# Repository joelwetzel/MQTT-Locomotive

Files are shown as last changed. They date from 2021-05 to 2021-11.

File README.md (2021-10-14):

# MQTT-Locomotive

**Topics**

[Retrofit a conventional locomotive](Documentation/RetrofitALocomotive/README.md)

[Engine Microcontroller](Documentation/EngineMicrocontroller/README.md)

[Sound Microcontroller](Documentation/SoundMicrocontroller/README.md)

[Tach Calibrator](Documentation/TachCalibrator/README.md)

[Whistle Controller](Documentation/WhistleController/README.md)

[Power Supply](Documentation/PowerSupply/README.md)

[Control Panel](Documentation/ControlPanel/README.md)

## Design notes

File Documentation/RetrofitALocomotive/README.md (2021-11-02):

## Remove the Shell

This one has a conventional E-Unit.  No sound system.  Incandescent headlights and cab light.

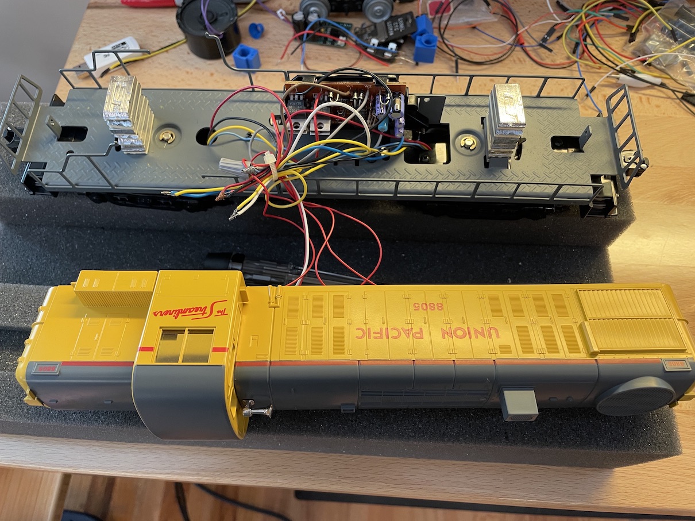
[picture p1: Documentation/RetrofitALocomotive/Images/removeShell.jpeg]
Remove the shell


---

## Cut wires and remove old E-Unit

Try to save as much wire as possible coming from the trucks, but don't worry about anything else.

This locomotive had weights stacked, creating a high center-of-gravity.  I'm going to relocate them down lower in the fuel tank.

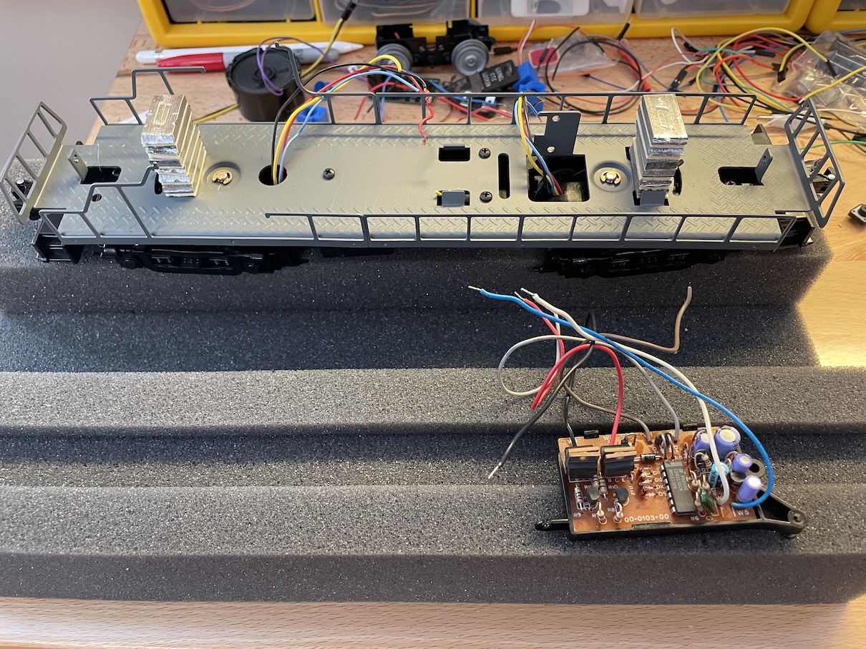
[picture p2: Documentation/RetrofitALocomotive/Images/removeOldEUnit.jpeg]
Cut wires


---

## Remove truck that will get the tachometer

Here I'm removing the front truck.  The opening for the wires is wider, which we'll need since we're adding extra wires for the tach.  We don't want it to resist turning.

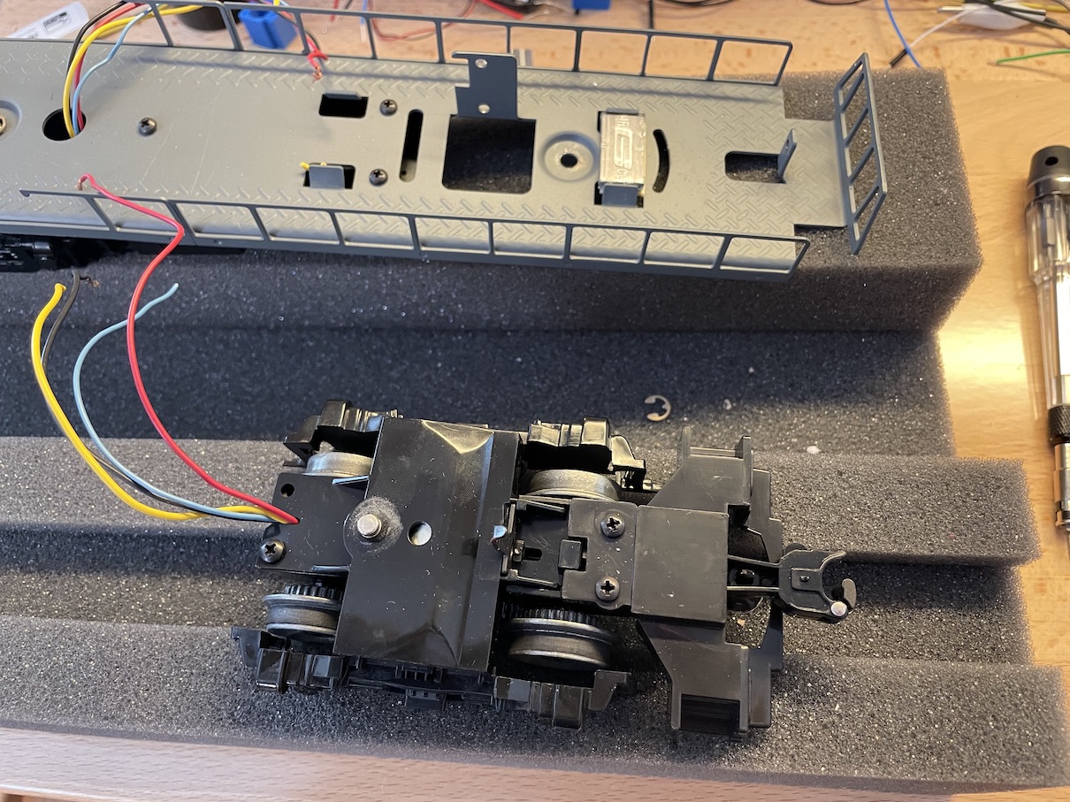
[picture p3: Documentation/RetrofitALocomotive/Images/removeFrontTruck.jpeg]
Remove front truck


---

## Wire/Glue/Test the tachometer

For this step, see [TachCalibrator Instructions](../TachCalibrator/README.md).

---

## Reinstall trucks

Here I have painted the trucks, and reinstalled them.  I have also moved most of the weights down into the fuel tank.

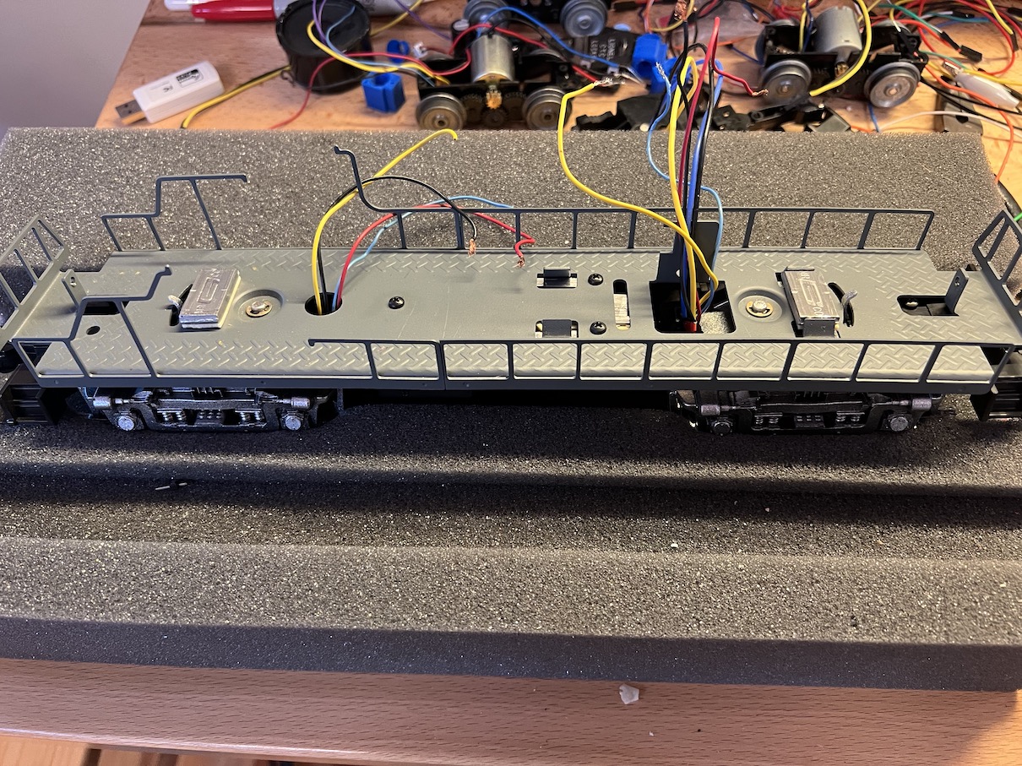
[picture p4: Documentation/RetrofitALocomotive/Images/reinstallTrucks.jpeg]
Reinstall trucks


---

## Power the motors

Install the motor driver and wire the truck motors to it.  Make sure to have lots of slack in these wires, because the trucks will turn and you don't want it to bind.

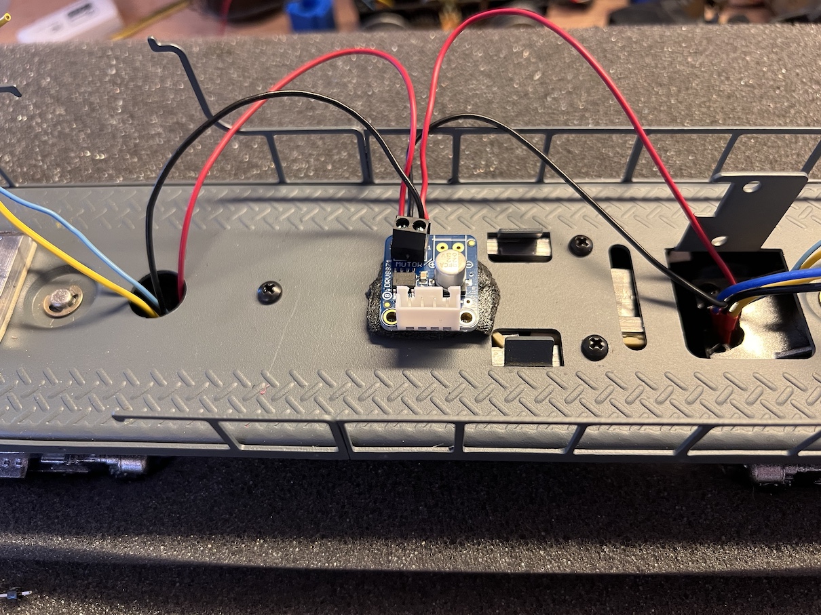
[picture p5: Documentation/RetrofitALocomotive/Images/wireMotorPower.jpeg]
Power the motors


---

## Power the smokestack

The motor driver for the smokestack needs an extra jumper soldered in on the back, from pin 1 to pin 4.

TODO

---

## Prepare the LED lights

This Alco RS-3 has dual headlights and a cab light.  I convert them to LEDs, and use heatshrink wrap to clean up the packaging.

It's important to solder a resistor in series.  I use 100ohm for the cab light, and 47ohm for the headlights.

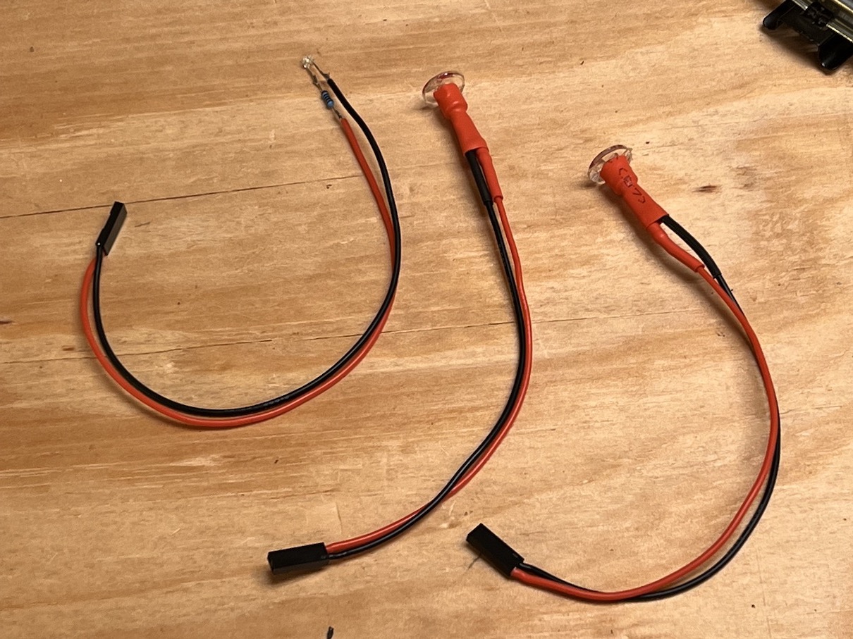
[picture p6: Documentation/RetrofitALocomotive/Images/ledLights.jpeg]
LED lights


You can reinstall them right away.

---

## Assemble and program the engine microcontroller and hat

1. Assemble the Wemos D1 Mini and the Engine Hat.  The Engine Microcontroller is detailed [here](../EngineMicrocontroller/README.md).
2. Build and upload the engine firmware.

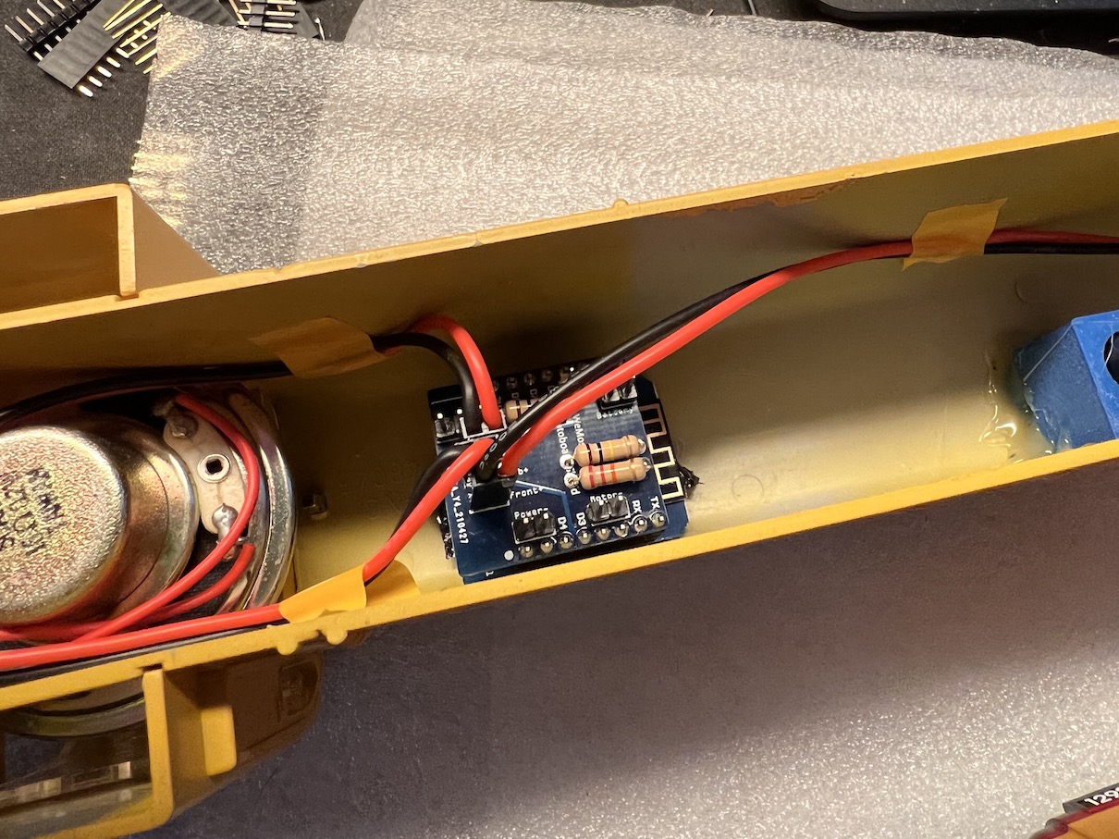
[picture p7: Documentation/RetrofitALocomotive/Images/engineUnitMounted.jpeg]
Mount the engine unit


---

## Assemble and program the sound microcontroller and hat

1. Assemble the Wemos D1 Mini and the Sound Hat.  The Sound Hat is detailed [here](../SoundMicrocontroller/README.md).
1. Build and upload the filesystem image.  It has the sound files.
2. Build and upload the sound firmware.
3. Test the sound.  You'll have both the engine and the sound ESP8266's still outside the chassis at this point.
4. Mount it in the body, with the usb port accessible.

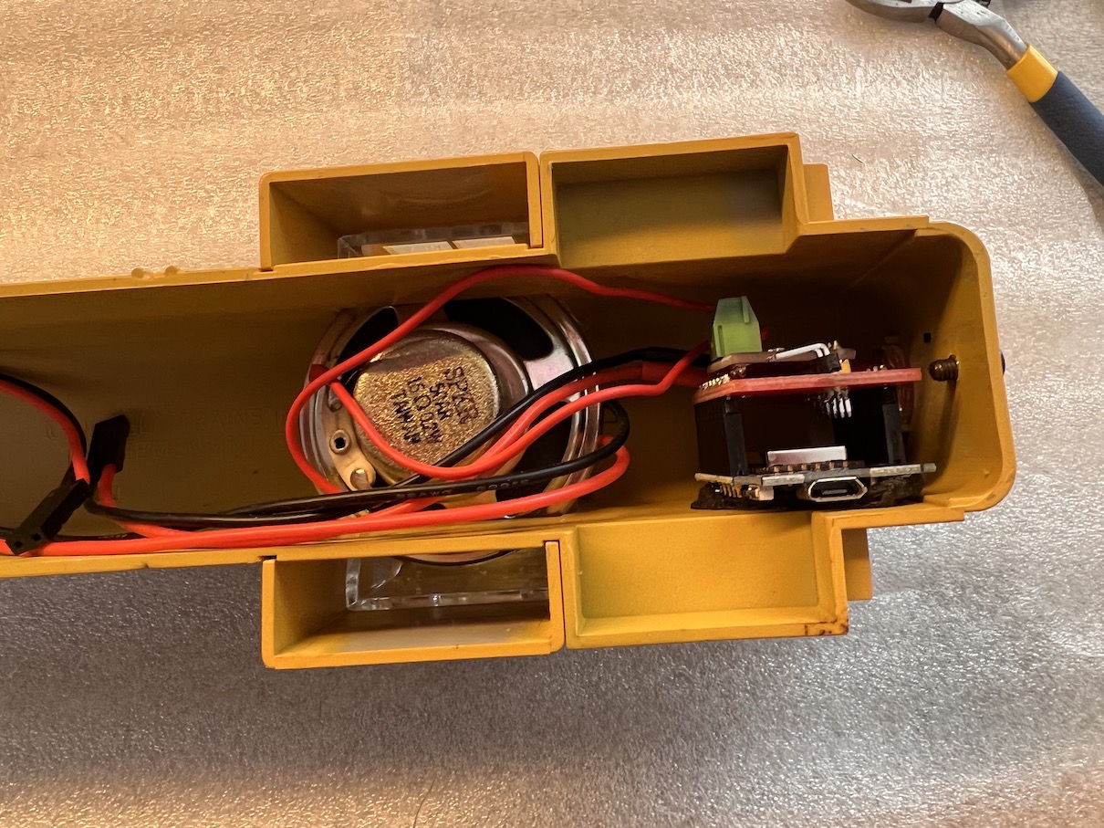
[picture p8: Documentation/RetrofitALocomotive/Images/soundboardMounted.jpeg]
Soundboard mounted


---

## Assemble the Power Supply PCB

The power supply is detailed [here](../PowerSupply/README.md).

---

** Get power from the trucks

Wire the truck power wires together and onto a Dupont connector that will go up to the power supply board.  Make sure to leave lots of slack.  The trucks will turn and you don't want it to bind.

I use twist connectors instead of soldered joints, because you might need to drop the trucks from the frame, while doing future maintenance.

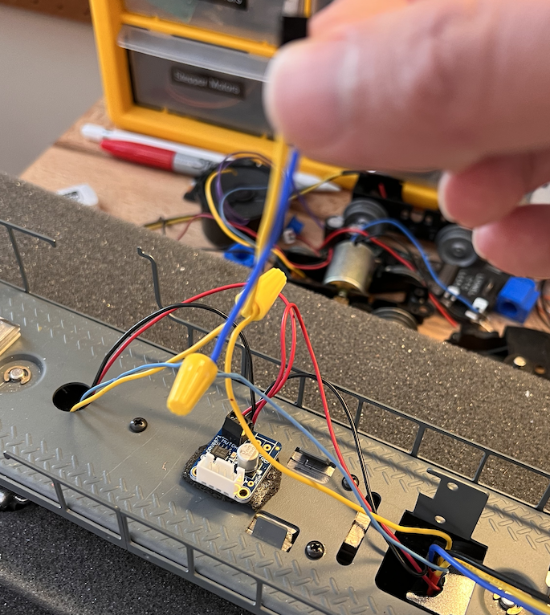
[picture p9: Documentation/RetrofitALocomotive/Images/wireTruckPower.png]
Wires from trucks


---

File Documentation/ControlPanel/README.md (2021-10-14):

# Control Panel

Here's the panel components wired up and tested, but not mounted in the panel yet:

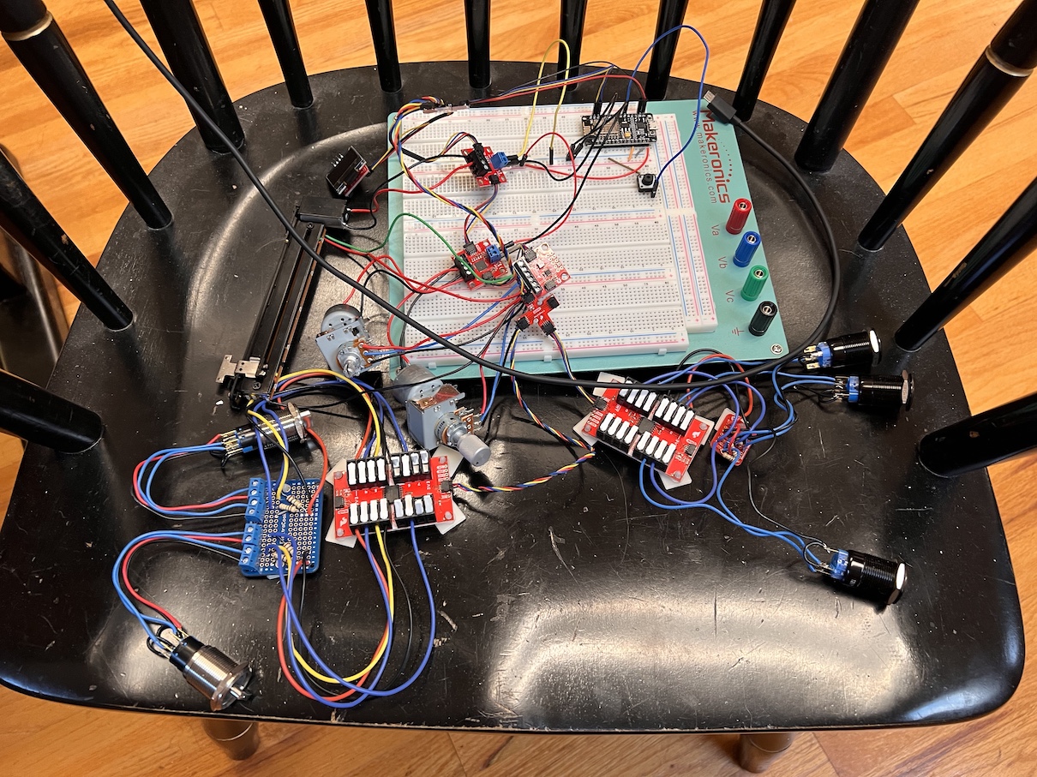
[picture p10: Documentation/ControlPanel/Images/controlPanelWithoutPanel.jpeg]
Control panel, sans panel


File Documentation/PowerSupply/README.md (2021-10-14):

# Power Supply

This board takes track power (~16V AC) as input.  It then:
- Rectifies to DC
- Smooths the waveform
- Provides 16V DC output
- Provides 5V DC output

---

## Fritzing File

[Fritzing file](PowerSupply.fzz)

---

## Schematic

Note: The pin labels on the buck converter in the lower-right are wrong.  Ignore them and wire up as shown in the PCB and Breadboard diagrams.

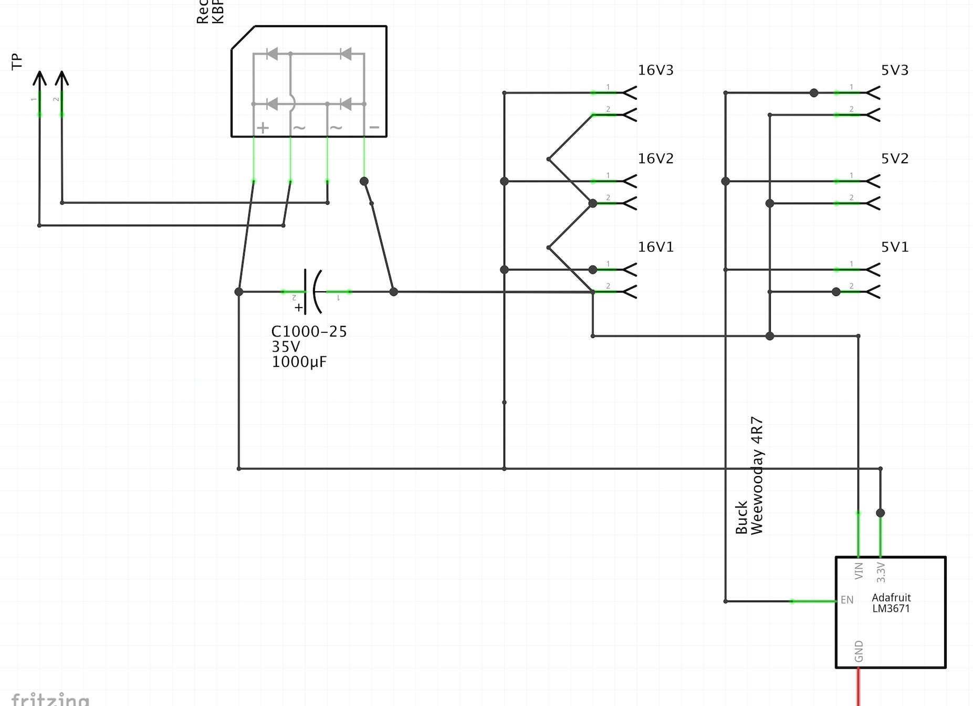
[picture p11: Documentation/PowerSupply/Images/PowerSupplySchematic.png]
Schematic


---

## Breadboard

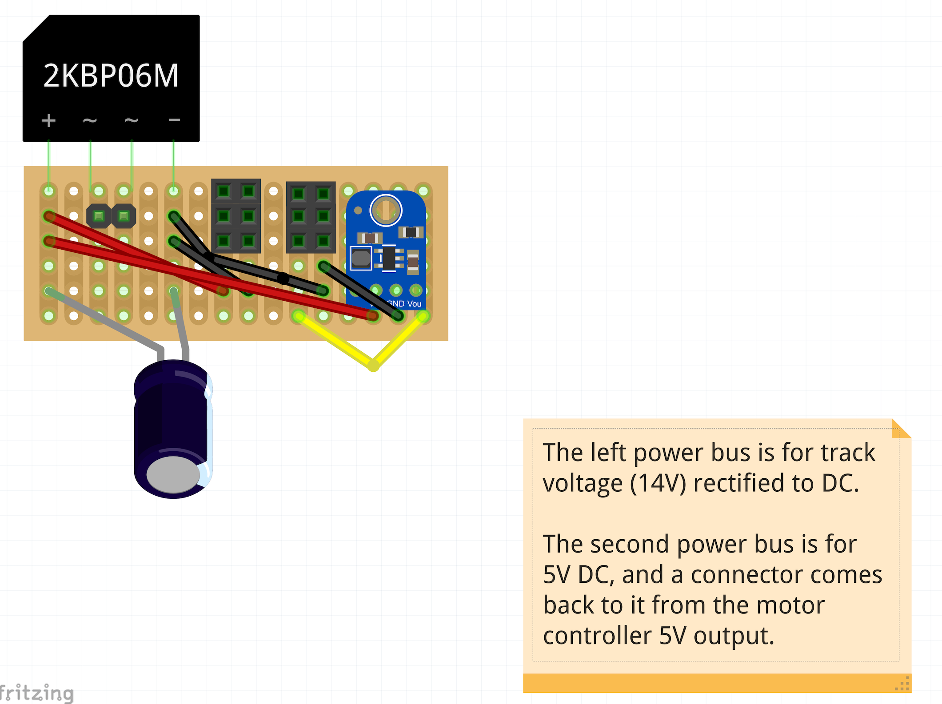
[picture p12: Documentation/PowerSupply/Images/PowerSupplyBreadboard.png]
Breadboard


---

## PCB

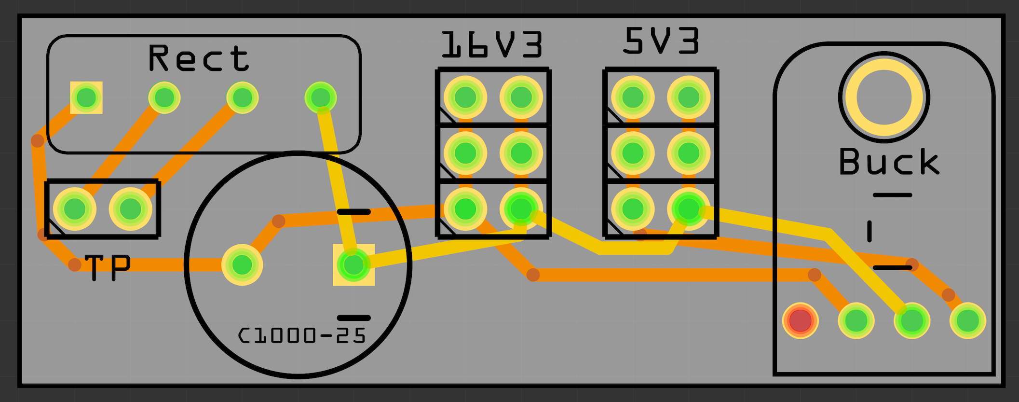
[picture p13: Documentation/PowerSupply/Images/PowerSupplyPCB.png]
PCB


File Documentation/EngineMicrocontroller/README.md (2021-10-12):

# Engine Microcontroller

The engine microcontroller controls:
- Motor power
- Smoke power
- Lights
- Tachometer
- Running the locomotive simulation

---

## Firmware
The firmware is in the /LocoEngine folder of this repo.

---

## Fritzing File
[Fritzing file](EngineHat.fzz)

---

## Schematic

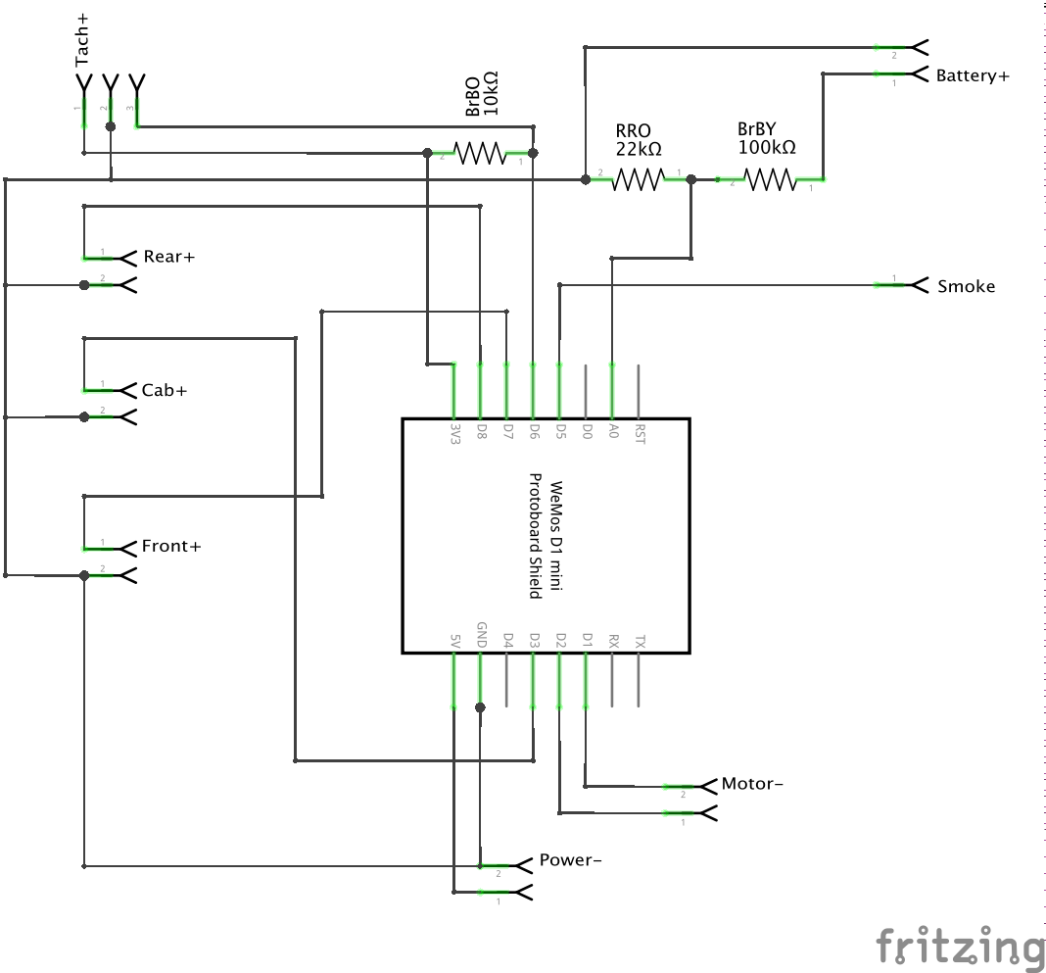
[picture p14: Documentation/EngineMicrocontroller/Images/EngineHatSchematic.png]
Fritzing schematic of Engine Hat


---

## PCB Hat

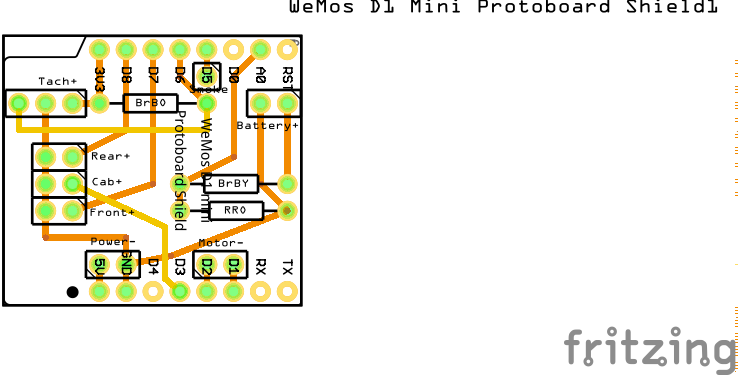
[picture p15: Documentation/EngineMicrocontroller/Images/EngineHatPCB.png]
Fritzing pcb for Engine Hat


---

## Breadboard

In the actual locomotives, I use the PCB hat, but this breadboard diagram is useful for showing the external wiring and connections.  (Such as to the motor drivers.)

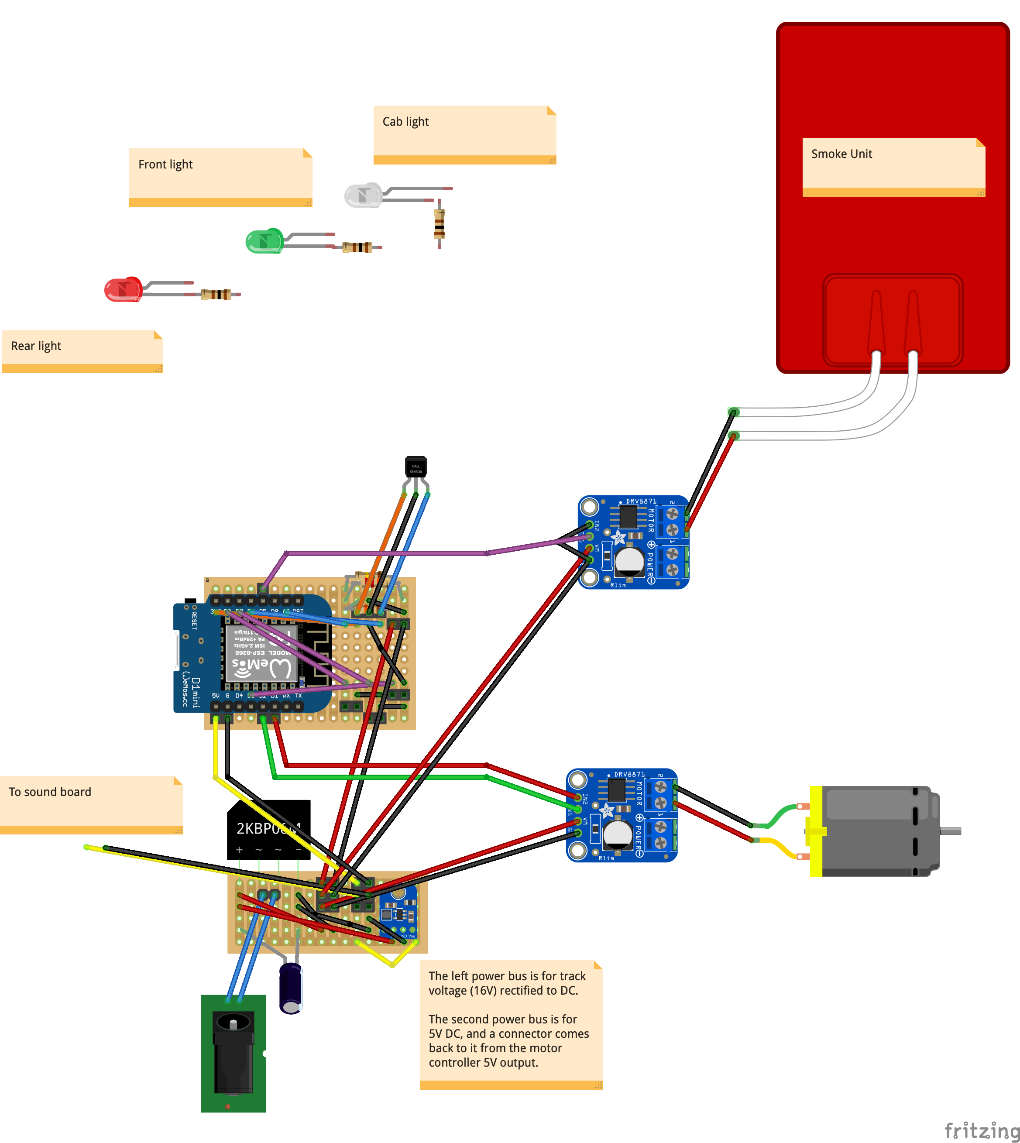
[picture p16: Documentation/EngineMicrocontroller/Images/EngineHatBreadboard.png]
Fritzing breadboard for Engine Hat


---

## Assembled

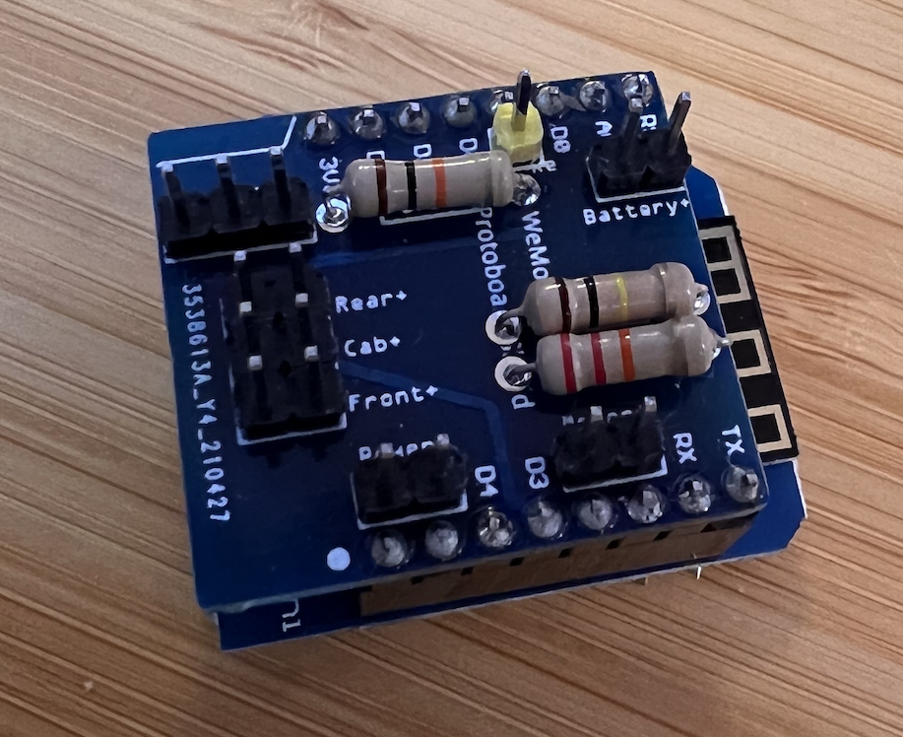
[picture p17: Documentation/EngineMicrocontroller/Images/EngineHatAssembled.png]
Engine hat assembled


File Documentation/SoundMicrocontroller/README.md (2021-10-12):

# Sound Microcontroller

The Sound Microcontroller listens for events from the Engine Microcontroller, and outputs synthesized sounds.

---

## Firmware
The firmware is in the /LocoSounds folder of this repo.

---

## Fritzing File
[Fritzing file](SoundHat.fzz)

---

## PCB

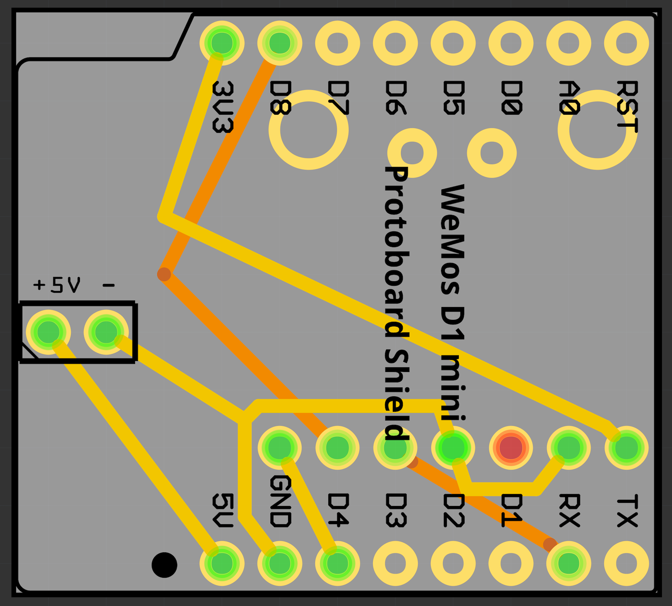
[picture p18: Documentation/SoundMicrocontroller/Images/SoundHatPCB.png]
Sound hat PCB


---

## Breadboard View
It's not actually assembled like this, but this picture helps explain the wiring.
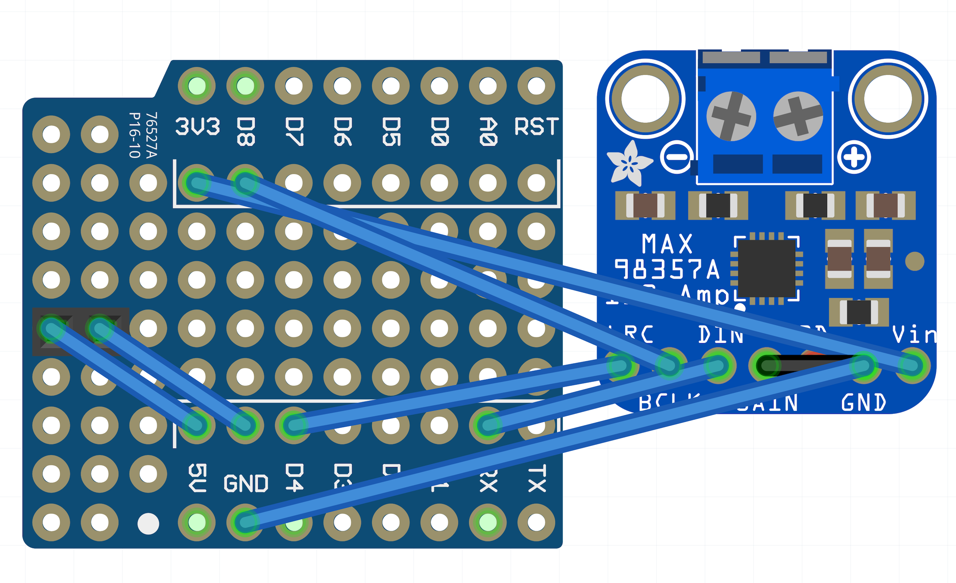
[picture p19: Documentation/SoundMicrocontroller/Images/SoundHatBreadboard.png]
Sound hat breadboard


---

## Assembled

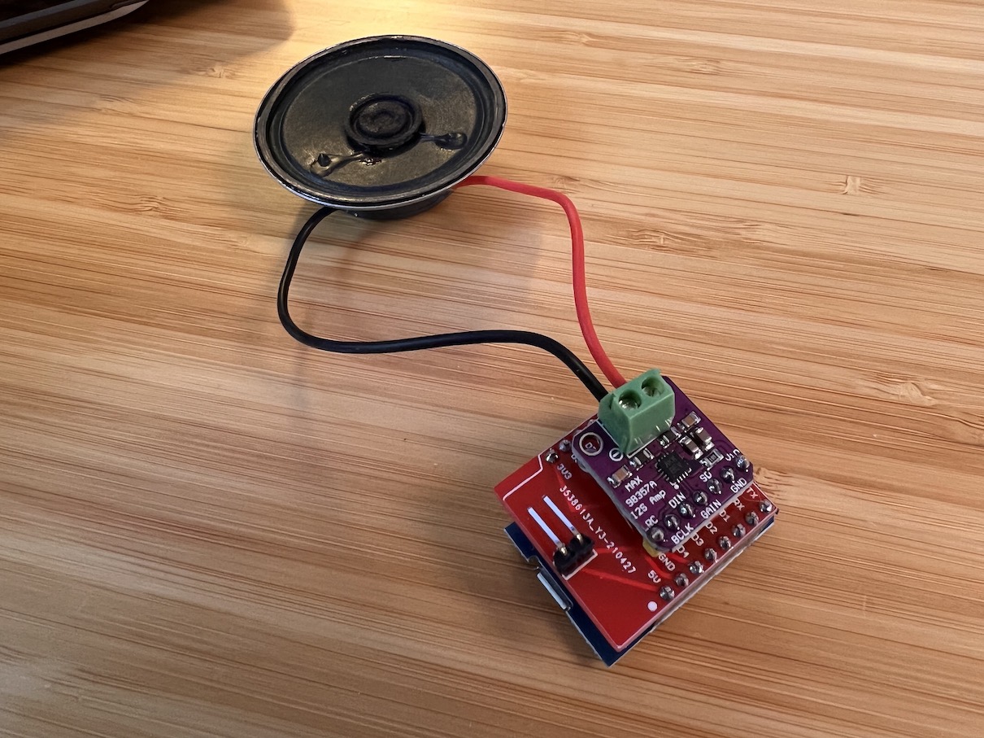
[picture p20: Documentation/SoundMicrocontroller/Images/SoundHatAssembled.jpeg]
Sound hat assembled


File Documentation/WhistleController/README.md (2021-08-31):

The whistle controller is a board that can be inserted in the ground path of an off-the-shelf conventional sound unit.  It listens for the same MQTT commands as the LocoSounds board, but instead of playing its own sounds, it controls the voltages going into a conventional sound unit, and lets that unit generate the sounds.

This means it can be used with Lionel TrainSounds, Williams TrueBlast, or others.

Here's the basic idea, borrowed from [this post](http://www.jcstudiosinc.com/Whistle-Button-Bell-Controller):

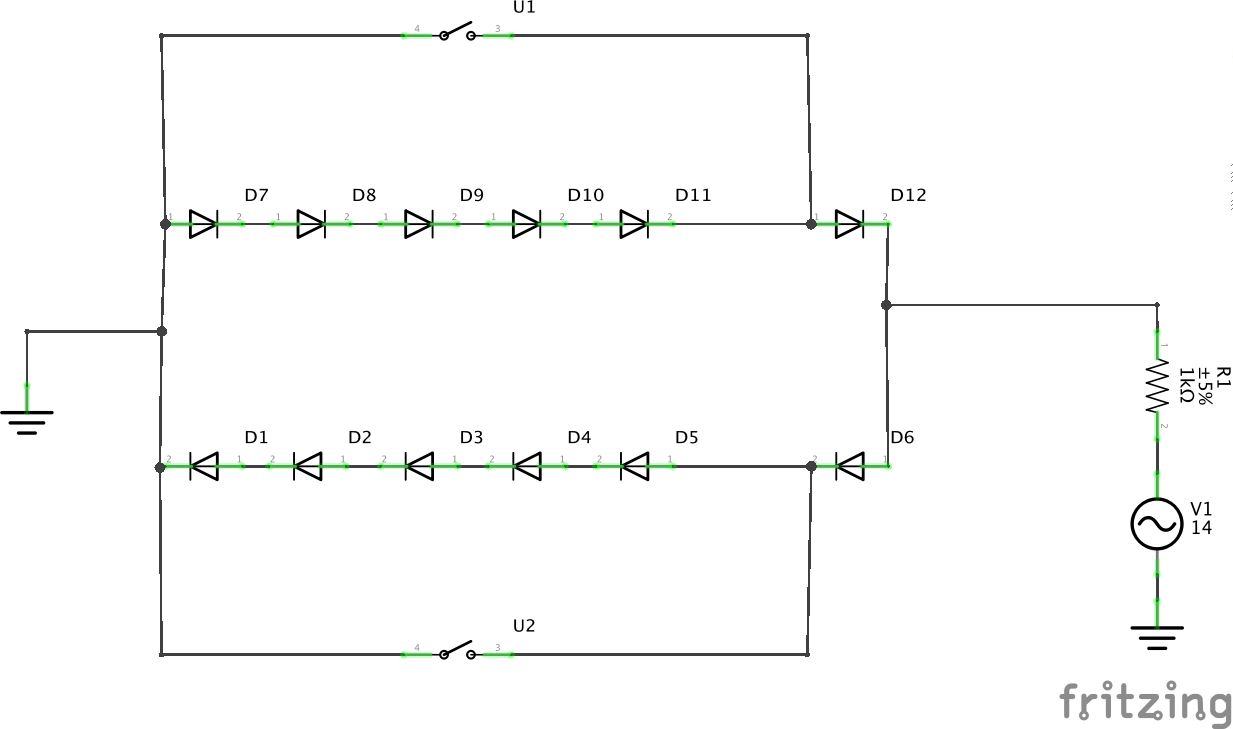
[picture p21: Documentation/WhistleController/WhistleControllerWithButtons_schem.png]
Whistle controller by buttons


- The resistor on the right represents a conventional sound board, such as a Williams TrueBlast.
- Closing either switch will cause the AC sine wave to shift either positive or negative.  One direction sounds the horn.  One direction toggles the bell.
- I have built and tested a prototype of this.

The next step in developing the idea is that instead of physical switches, we want to use transistors, so that eventually we can control this from an ESP8266.

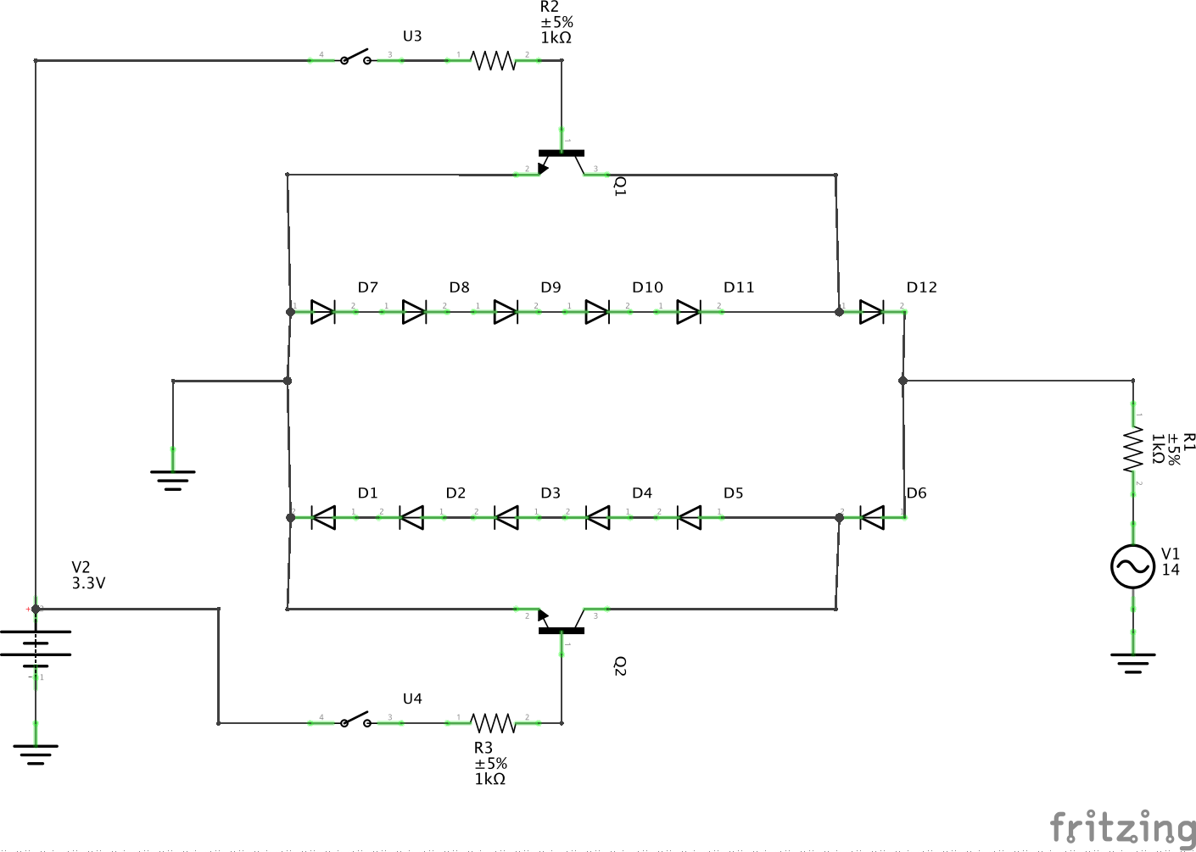
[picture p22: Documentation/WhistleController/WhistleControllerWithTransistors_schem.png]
Whistle controller with transistors


- These are NPN transistors.  The arrow side needs to be to ground, so this has to be "downstream" of the load.  Has to be on the ground side.
- R2 and R3 prevent a current rush from burning up the transistors.
- Switches U3 and U4 represent GPIO pins on the ESP8266 going to low or high.
- Note that I am trying to keep the grounds of the AC power and the DC microcontroller separate.  I'm not sure this is necessary, because eventually all grounds go together.  (The ESP8266 is powered by a rectifier circuit that comes from the AC.)  But it seemed like good practice to not create a bridge of ground from high-current AC that goes through the inside of my microcontroller.
- This is my next prototype to build.

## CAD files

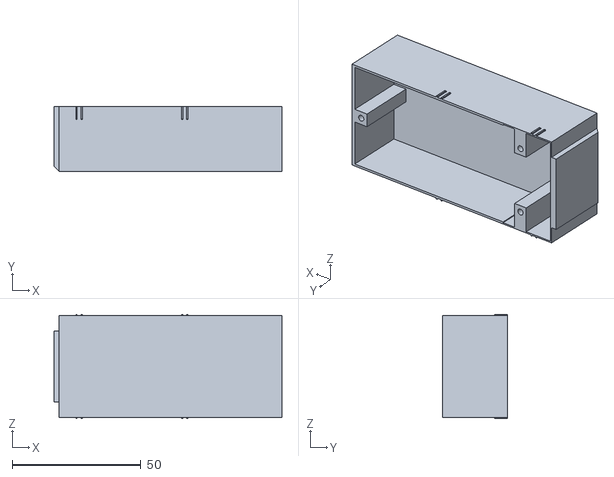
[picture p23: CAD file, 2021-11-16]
3d Printed Parts/Alco RS-3 Undercarriage (metal frame)/MainBox.stl
88.5 x 25.2 x 40.6

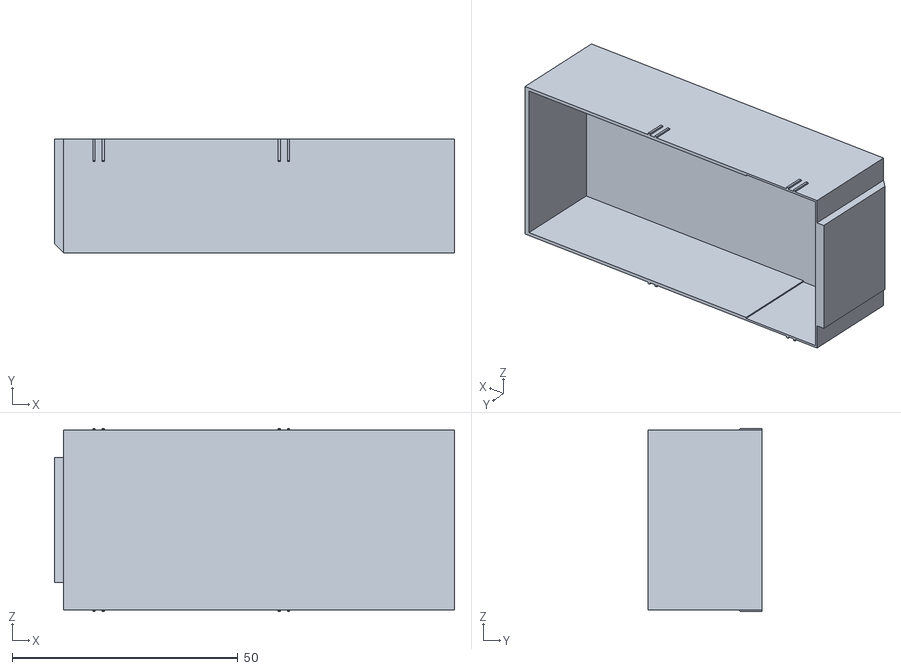
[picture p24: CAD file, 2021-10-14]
3d Printed Parts/Alco RS-3 Undercarriage (plastic frame)/MainBox.stl
88.5 x 25.2 x 40.6

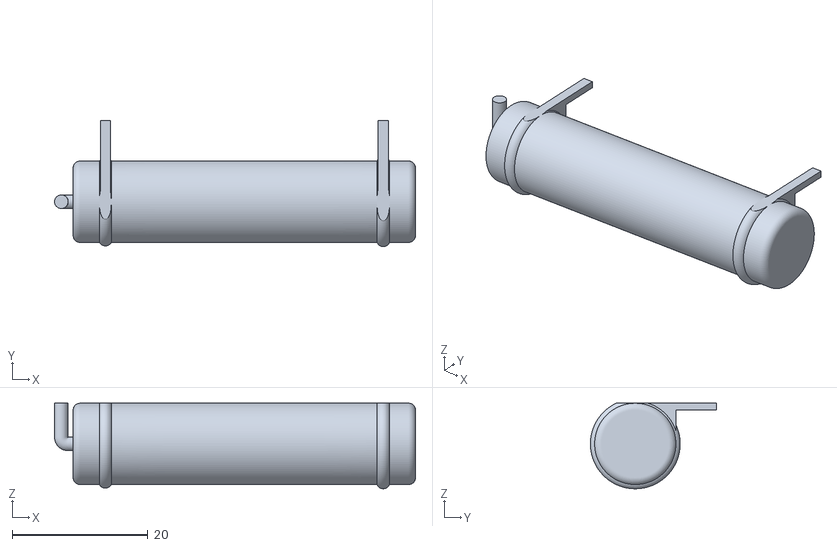
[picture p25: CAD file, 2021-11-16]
3d Printed Parts/Alco RS-3 Undercarriage (plastic frame)/RightTank.stl
53.2 x 18.6 x 12.6

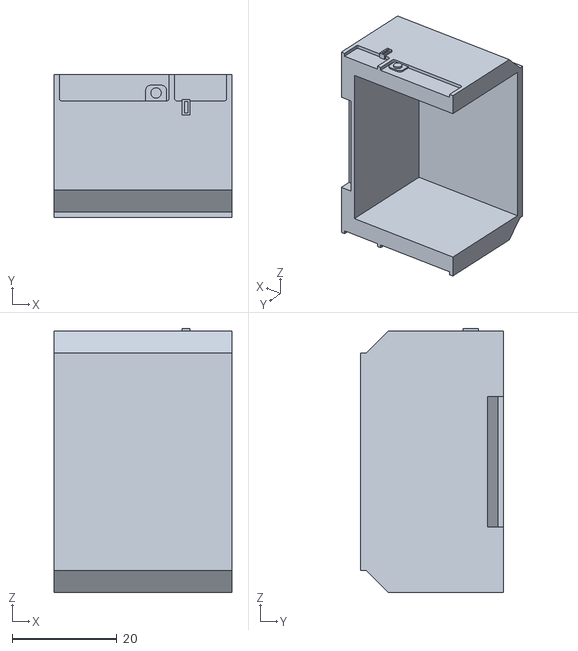
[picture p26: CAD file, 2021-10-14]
3d Printed Parts/Alco RS-3 Undercarriage (plastic frame)/OuterBox.stl
34.0 x 27.2 x 50.5

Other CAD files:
3d Printed Parts/Alco RS-3 Undercarriage (metal frame)/LeftTank.stl
3d Printed Parts/Alco RS-3 Undercarriage (plastic frame)/LeftTank.stl
3d Printed Parts/Alco RS-3 Undercarriage (metal frame)/RightTank.stl

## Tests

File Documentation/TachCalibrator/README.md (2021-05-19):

This board is a tool for testing and calibrating a Lionel truck with the Hall Effect tachometer onboard.  Use the TachCalibrator firmware.  It will send data to MQTT.

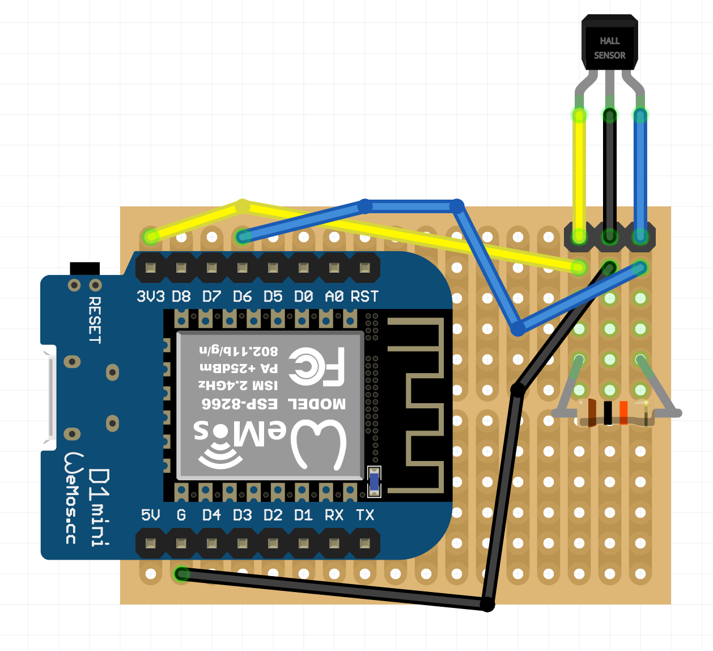
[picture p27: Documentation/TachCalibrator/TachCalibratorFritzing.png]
Fritzing diagram of Tach Calibrator


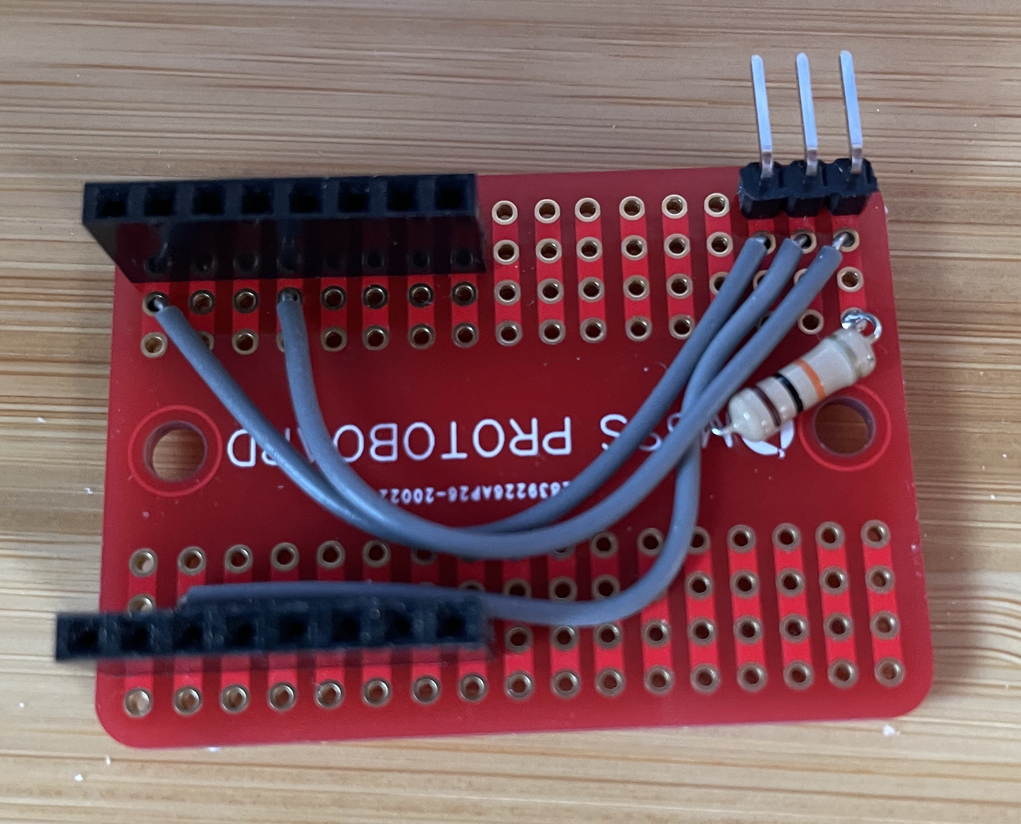
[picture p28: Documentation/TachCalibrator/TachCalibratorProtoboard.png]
Photo of Tach Calibrator protoboard


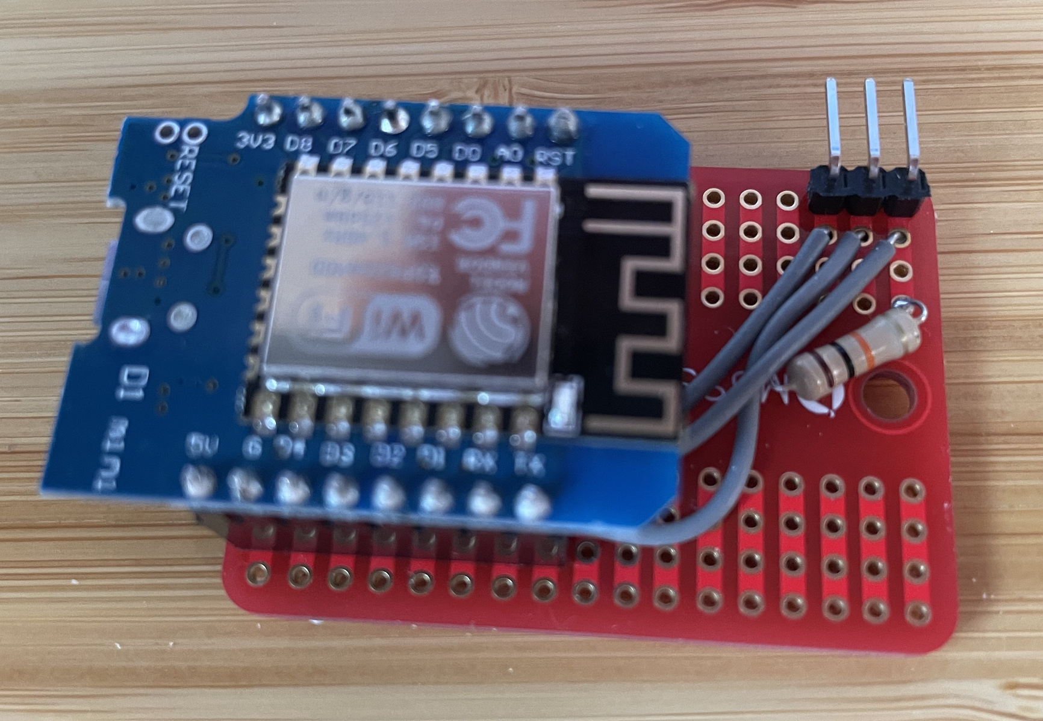
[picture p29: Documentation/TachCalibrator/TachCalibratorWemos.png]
Photo of protoboard with Wemos D1 Mini


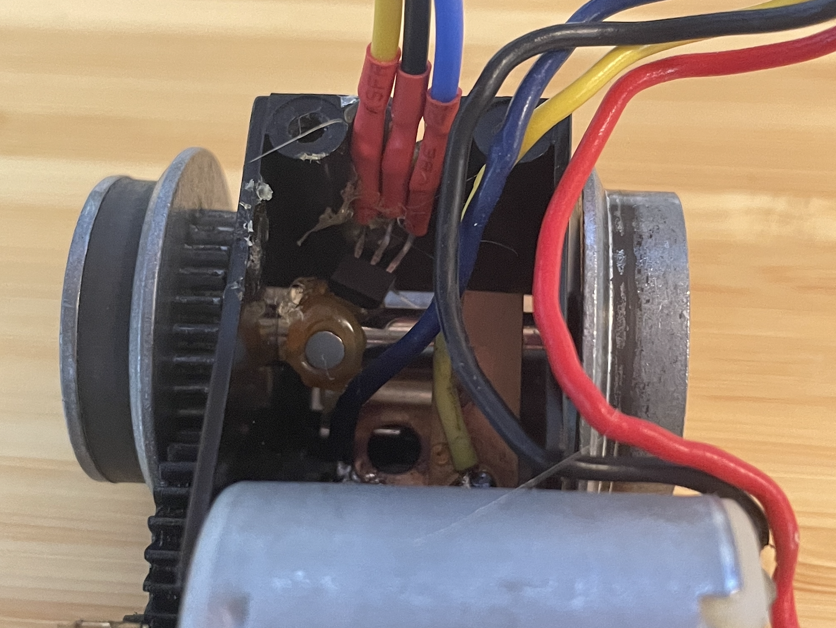
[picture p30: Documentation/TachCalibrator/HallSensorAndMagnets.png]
Photo of the Hall Effect sensor and magnets in the truck


**Testing out my homemade tach on a powered Lionel truck:**

Video of a tach test (http://www.youtube.com/watch?v=zW3miqPo4ug "Testing out my homemade tach on a powered Lionel truck.")

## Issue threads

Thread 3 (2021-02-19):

Layout a prototype board that will fit everything into a Beep shell.

joelwetzel, 2021-02-19:

joelwetzel, 2021-04-07:
I think a Wemos hat is the most likely way to get this done.  Not sure if I can also fit in sounds though.

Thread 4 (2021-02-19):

Solder more LED light fixtures

joelwetzel, 2021-02-19:

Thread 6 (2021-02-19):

Design and 3d print a fixture to hold the smoke tube.

joelwetzel, 2021-02-19:

joelwetzel, 2021-03-31:
Done

Closed 2021-03-31.

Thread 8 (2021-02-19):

Implement a Multiple-Unit train control device

joelwetzel, 2021-02-19:
For double-heading locomotives.  Should this be entirely a software component?  Or do I care enough to build it onto an ESP with lcd screen and some buttons?

joelwetzel, 2021-03-19:
I'm thinking maybe a series of command-line tools.

joelwetzel, 2021-03-31:
Ended up being a command you could send to the slave locos, to tell them to listen to and follow the master loco.

Closed 2021-03-31.

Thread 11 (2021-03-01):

Output attributes that are more physical

joelwetzel, 2021-03-01:
- True Engine RPMs
- Calculated Wheel RPMs
- Calculated ground speed
- Measured wheel RPMs (after building a hall-effect wheel encoder.)

joelwetzel, 2021-03-01:
Engine RPM is now explicitly calculated.

Closed 2021-03-02.

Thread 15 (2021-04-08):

PID controller isn't properly handling direction of travel.

joelwetzel, 2021-04-08:
Will need to track direction of travel too.  Not just speed and reverser state.

joelwetzel, 2021-04-09:
Fixed.

Closed 2021-04-09.

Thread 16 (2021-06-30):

Bug: Headlights control won't move by itself.

joelwetzel, 2021-06-30:
Right now the headlights control only moves itself if you change selected locos.  But there can be cases where it should move because things changed on the loco itself.

Repro:
1) Turn on master switch
2) Set headlights to on
3) Turn off master switch

Observed:  Headlights control stays in on position.
Expected: Headlights value in MQTT changed.  The control should move to match it.

(This does not apply to the reverser though.  Real reverser is a physical lever.  It doesn't move just because master switch turns off.)

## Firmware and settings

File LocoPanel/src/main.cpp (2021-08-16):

#include <Arduino.h>
#include <SimpleTimer.h>    // https://github.com/marcelloromani/Arduino-SimpleTimer/tree/master/SimpleTimer
#include <PubSubClient.h>   // https://github.com/knolleary/pubsubclient
#include <math.h>

#include <SPI.h>
#include <Wire.h>
#include <Adafruit_GFX.h>
#include <Adafruit_SSD1306.h>
#include <SparkFun_TCA9534.h>                   // QWIIC GPIO
#include <SparkFun_ADS1015_Arduino_Library.h>   // QWIIC ADC
#include <SCMD.h>                               // QWIIC motor driver
#include <SCMD_config.h>

#include "config.h"

#include "mqttHandler.h"
#include "locoList.h"
#include "locoStateCache.h"
#include "locoDisplayController.h"
#include "nextLocoButtonController.h"
#include "masterSwitchController.h"
#include "engineOnController.h"
#include "reverserController.h"
#include "headlightsController.h"
#include "throttleController.h"
#include "cablightsController.h"
#include "bellController.h"
#include "hornController.h"

/*****************  START GLOBALS SECTION ***********************************/

WiFiClient espClient;
PubSubClient mqttClient(espClient);
SimpleTimer timer;

Adafruit_SSD1306 locoDisplay(SCREEN_WIDTH, SCREEN_HEIGHT, &Wire, OLED_RESET);
TCA9534 qwiicGpio1;
TCA9534 qwiicGpio2;
ADS1015 qwiicAdc;
SCMD qwiicMotorDriver1;
SCMD qwiicMotorDriver2;

LocoList locoList;
LocoStateCache locoStateCache;
LocoDisplayController locoDisplayController(locoList, locoDisplay);
MqttHandler mqttHandler(mqttClient, locoList, locoStateCache, locoDisplayController);

NextLocoButtonController nextLocoButtonController(locoDisplayController);
MasterSwitchController masterSwitchController(mqttHandler, qwiicGpio2);
EngineOnController engineOnController(mqttHandler, qwiicGpio2);
ReverserController reverserController(mqttHandler, qwiicAdc, qwiicMotorDriver1);
HeadlightsController headlightsController(mqttHandler, qwiicAdc, qwiicMotorDriver1);
CablightsController cablightsController(mqttHandler, qwiicGpio1);
ThrottleController throttleController(mqttHandler, qwiicAdc, qwiicMotorDriver2);
BellController bellController(mqttHandler, qwiicGpio1);
HornController hornController(mqttHandler, qwiicGpio1);

/*****************  END GLOBALS SECTION ***********************************/


void processStep()
{
  nextLocoButtonController.ProcessStep();
  locoDisplayController.ProcessStep();

  LocoState currentState = locoStateCache.GetStateFor(locoDisplayController.GetSelectedRoadname());

  masterSwitchController.ProcessStep(currentState);
  engineOnController.ProcessStep(currentState);
  reverserController.ProcessStep(currentState);
  headlightsController.ProcessStep(currentState);
  cablightsController.ProcessStep(currentState);
  throttleController.ProcessStep(currentState);
  bellController.ProcessStep(currentState);
  hornController.ProcessStep(currentState);

  mqttHandler.ProcessStep();
}

void setup() {
  Serial.begin(115200);
  Wire.begin();

  delay(1000);

  // Initialize Qwiic GPIO
  Serial.println("Looking for Qwiic GPIO 1...");
  if (qwiicGpio1.begin(Wire, 0x27) == false) {
    Serial.println("Check connections.  No Qwiic GPIO 1 detected.");
    while (1);
  }
  Serial.println("Found Qwiic GPIO 1.");

  Serial.println("Looking for Qwiic GPIO 2...");
  if (qwiicGpio2.begin(Wire, 0x26) == false) {
    Serial.println("Check connections.  No Qwiic GPIO 2 detected.");
    while (1);
  }
  Serial.println("Found Qwiic GPIO 2.");

  // Initialize Qwiic ADC
  Serial.println("Looking for Qwiic ADC...");
  if (qwiicAdc.begin() == false) {
    Serial.println("Check connections.  No Qwiic ADC detected.");
    while (1);
  }
  Serial.println("Found Qwiic ADC.");

  // Initialize Qwiic Motor Driver 1
  qwiicMotorDriver1.settings.commInterface = I2C_MODE;
  qwiicMotorDriver1.settings.I2CAddress = 0x5D;
  Serial.println("Looking for Qwiic Motor Driver 1...");
  while (qwiicMotorDriver1.begin() != 0xA9)
  {
    Serial.println("Motor Driver (1) ID mismatch, trying again.");
    delay(500);
  }
  while (qwiicMotorDriver1.ready() == false)
  {
    ;
  }
  while (qwiicMotorDriver1.busy())
  {
    ;
  }
  qwiicMotorDriver1.enable();
  Serial.println("Found Qwiic Motor Driver 1.");

  // Initialize Qwiic Motor Driver 2
  qwiicMotorDriver2.settings.commInterface = I2C_MODE;
  qwiicMotorDriver2.settings.I2CAddress = 0x5E;
  Serial.println("Looking for Qwiic Motor Driver 2...");
  while (qwiicMotorDriver2.begin() != 0xA9)
  {
    Serial.println("Motor Driver (2) ID mismatch, trying again.");
    delay(500);
  }
  while (qwiicMotorDriver2.ready() == false)
  {
    ;
  }
  while (qwiicMotorDriver2.busy())
  {
    ;
  }
  qwiicMotorDriver2.enable();
  Serial.println("Found Qwiic Motor Driver 2.");

  pinMode(MQTT_CONNECTED_PIN, OUTPUT);

  masterSwitchController.Setup();
  engineOnController.Setup();
  reverserController.Setup();
  headlightsController.Setup();
  cablightsController.Setup();
  throttleController.Setup();
  bellController.Setup();
  hornController.Setup();

  locoDisplayController.Setup(); // Do this before mqttHandler.Setup(), so that it displays the loading screen while connecting to wifi.

  mqttHandler.Setup();

  nextLocoButtonController.Setup();

  timer.setInterval(15, processStep);
}


void loop() {
  mqttHandler.Loop();
  timer.run();
}

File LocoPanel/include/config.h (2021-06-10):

#ifndef CONFIG_H
#define CONFIG_H


// Include file that contains WiFi credentials.  The #defines that need to be in it are:  WIFI_SSID, WIFI_PASSWORD
#include "wifi.h"
#define USER_MQTT_SERVER          "mqtt.local"
#define USER_MQTT_PORT            1883


#define MQTT_CONNECTED_PIN        2


#define SCREEN_WIDTH 128
#define SCREEN_HEIGHT 64

#define OLED_RESET 16
#define SCREEN_ADDRESS 0x3C



#endif

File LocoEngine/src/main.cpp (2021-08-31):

#include <Arduino.h>
#include <SimpleTimer.h>    // https://github.com/marcelloromani/Arduino-SimpleTimer/tree/master/SimpleTimer
#include <PubSubClient.h>   // https://github.com/knolleary/pubsubclient
#include <math.h>

#include "config.h"

#include "iControlModel.h"
#include "simulatorControlModel.h"
#include "toyControlModel.h"
#include "muSlaveControlModel.h"

#include "pidController.h"
#include "motorDriver.h"
#include "mqttHandler.h"
#include "lightingDriver.h"
#include "soundController.h"
#include "batteryDriver.h"
#include "smokeDriver.h"
#include "tachDriver.h"


/*****************  START GLOBALS SECTION ***********************************/

WiFiClient espClient;
PubSubClient mqttClient(espClient);
SimpleTimer timer;

BatteryDriver batteryDriver;

SimulatorControlModel refSimulatorControlModel(batteryDriver);
IControlModel* ptrSimulatorControlModel(&refSimulatorControlModel);

ToyControlModel refToyControlModel(batteryDriver);
IControlModel* ptrToyControlModel(&refToyControlModel);

MuSlaveControlModel refMuControlModel(batteryDriver);
IControlModel *ptrMuControlModel(&refMuControlModel);

#ifdef SIMULATOR_CONTROL_MODEL
IControlModel* ptrControlModel = ptrSimulatorControlModel;
#elif defined TOY_CONTROL_MODEL
IControlModel* ptrControlModel = ptrToyControlModel;
#elif defined MU_SLAVE_CONTROL_MODEL
IControlModel* ptrControlModel = ptrMuControlModel;
#endif

PidController pidController;
MotorDriver motorDriver;
SmokeDriver smokeDriver;
TachDriver tachDriver;
LightingDriver lightingDriver(ptrControlModel, batteryDriver);
SoundController soundController(batteryDriver);

MqttHandler mqttHandler(mqttClient, ptrControlModel, lightingDriver, soundController, batteryDriver, smokeDriver, tachDriver, pidController);

float _previousMotorSpeed;

/*****************  END GLOBALS SECTION ***********************************/

void changeControlModel(IControlModel* newPtr)
{
  ptrControlModel = newPtr;
  lightingDriver.ChangeControlModel(newPtr);
  mqttHandler.ChangeControlModel(newPtr);
}


void processStep()
{
  batteryDriver.ProcessStep();
  ptrControlModel->ProcessStep();

#ifdef DIRECT_SPEED_CONTROL
  motorDriver.SetMotorSpeed(ptrControlModel->GetSpeedPercent() * ptrControlModel->GetDirectionOfTravel());
#elif defined PID_SPEED_CONTROL
  float desiredWheelRpms = ptrControlModel->GetEstimatedWheelRpms();
  float measuredWheelRpms = tachDriver.GetWheelRpm();
  pidController.Update(desiredWheelRpms, measuredWheelRpms, micros());
  float controlledMotorPercent = pidController.GetControlValue();
  controlledMotorPercent = _previousMotorSpeed + (controlledMotorPercent - _previousMotorSpeed) / 3.0;
  motorDriver.SetMotorSpeed(controlledMotorPercent * ptrControlModel->GetDirectionOfTravel());
  _previousMotorSpeed = controlledMotorPercent;
#endif

  smokeDriver.SetSmokePercent(ptrControlModel->GetSmokePercent());
  tachDriver.ProcessStep();
  lightingDriver.ProcessStep();
  soundController.ProcessStep();

  mqttHandler.ProcessStep();
}


void setup()
{
  _previousMotorSpeed = 0.0;

  Serial.begin(9600);

  pinMode(MQTT_CONNECTED_PIN, OUTPUT);

  // Flash the LED for just a moment before trying to connect to MQTT.  The LED will come back on permanently when connected.
  pinMode(MQTT_CONNECTED_PIN, 0);
  delay(500);
  pinMode(MQTT_CONNECTED_PIN, 1);

  motorDriver.Setup();
  smokeDriver.Setup();
  tachDriver.Setup();
  mqttHandler.Setup();
  lightingDriver.Setup();
  soundController.Setup();
  batteryDriver.Setup();

  delay(10);
  
  timer.setInterval(PHYSICS_DELTAT, processStep);   
}


void loop()
{
  mqttHandler.Loop();

  int desiredControlModelId = mqttHandler.GetDesiredControlModelId();
  if (desiredControlModelId != ptrControlModel->GetControlModelId() && ptrControlModel->GetSpeedMph() < 1)
  {
    if (desiredControlModelId == 1)
    {
      changeControlModel(ptrSimulatorControlModel);
    }
    else if (desiredControlModelId == 2)
    {
      changeControlModel(ptrToyControlModel);
    }
    else if (desiredControlModelId == 3)
    {
      changeControlModel(ptrMuControlModel);
    }
  }

  timer.run();
}

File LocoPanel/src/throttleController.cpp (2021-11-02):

#include "throttleController.h"
#include <Arduino.h>

ThrottleController::ThrottleController(MqttHandler &mqttHandler, ADS1015 &qwiicAdc, SCMD &qwiicMotorDriver)
    : _mqttHandler(mqttHandler), _qwiicAdc(qwiicAdc), _qwiicMotorDriver(qwiicMotorDriver)
{
    lastKnownDetent = -1;

    resetCounter = 0;
    currentThrottleMode = ControllerMode::Unknown;

    currentLocoRoadName = "";
}


void ThrottleController::Setup()
{
    _qwiicAdc.setGain(ADS1015_CONFIG_PGA_1);        // This gain will get us readings from 0..1660
}


int ThrottleController::convertThrottleToPowerDetent(float throttle)
{
    int detent = map(throttle, 0, 100, 0, POWER_LEVELS);
    detent = constrain(detent, 0, POWER_LEVELS);
    return detent;
}


float ThrottleController::convertPowerDetentToThrottle(int powerDetent)
{
    float throttle = map(powerDetent, 0, POWER_LEVELS, 0, 100);
    throttle = constrain(throttle, 0.0, 100.0);
    return throttle;
}


float ThrottleController::measureThrottle()
{
    // Measure the slider position.
    uint16_t voltage = _qwiicAdc.getAnalogData(THROTTLE_ADC_PIN);
    //Serial.printf("voltage: %d\n", voltage);

    float measuredThrottle = ((float)voltage) / THROTTLE_MAX_VOLTAGE_READING * 100.0; // Between 0.0 - 100.0
    measuredThrottle = constrain(measuredThrottle, 0.0, 100.0);

    return measuredThrottle;
}


void ThrottleController::ProcessStep(LocoState currentLocoState)
{
    // Measure the slider position.
    float measuredThrottle = measureThrottle();

    // Did the selected loco change?  If so, reset the throttle to match the new loco.
    if (currentLocoState.RoadName != currentLocoRoadName)
    {
        Serial.println("Loco changed.  Resetting...");
        //Serial.println(currentLocoState.RoadName.c_str());
        //Serial.println(currentLocoRoadName.c_str());
        currentThrottleMode = ControllerMode::Resetting;
        currentLocoRoadName = currentLocoState.RoadName;
        resetCounter = 0;
    }

    // Behavior changes, depending on what mode we're in.
    if (currentThrottleMode == ControllerMode::Resetting)
    {
        // Serial.println("Resetting...");

        float desiredThrottle = currentLocoState.Throttle;
        float delta = fabs(measuredThrottle - desiredThrottle);
        uint8_t closingSpeed = 255;
        if (delta < 20.0)
        {
            closingSpeed = 210;
        }

        // Serial.printf("%f %f\n", desiredThrottle, measuredThrottle);

        if (delta < 2.0 || resetCounter > 50)
        {
            _qwiicMotorDriver.setDrive(THROTTLE_MOTOR_NUM, THROTTLE_UP, 0);
            currentThrottleMode = ControllerMode::AcceptingInput;
            Serial.println("Accepting input...");
            //Serial.printf("%f\n", measuredThrottle);
            lastKnownDetent = convertThrottleToPowerDetent(desiredThrottle);
        }
        else if (desiredThrottle > measuredThrottle)
        {
            // Serial.printf("+ %f %f\n", desiredThrottle, measuredThrottle);
            _qwiicMotorDriver.setDrive(THROTTLE_MOTOR_NUM, THROTTLE_UP, closingSpeed);
        }
        else if (desiredThrottle < measuredThrottle)
        {
            // Serial.printf("- %f %f\n", desiredThrottle, measuredThrottle);
            _qwiicMotorDriver.setDrive(THROTTLE_MOTOR_NUM, THROTTLE_DOWN, closingSpeed);
        }

        resetCounter++;
    }
    else if (currentThrottleMode == ControllerMode::AcceptingInput)
    {
        // Snap to a power level detent
        int closestDetent = convertThrottleToPowerDetent(measuredThrottle);
        float throttleOfClosestDetent = convertPowerDetentToThrottle(closestDetent);

        //Serial.printf("%f, %d, %f \n", measuredThrottle, closestDetent, throttleOfClosestDetent);
        
        // Are we close enough to the detent to be "there"?
        float offset = fabs(measuredThrottle - throttleOfClosestDetent);
        int detentPower = map((int)offset, 0, 6, 220, 235);

        if (offset < 2.0 ||
            (closestDetent == POWER_LEVELS && measuredThrottle > 96.0))
        {
            // We're at a detent
            _qwiicMotorDriver.setDrive(THROTTLE_MOTOR_NUM, THROTTLE_UP, 0);
            // Serial.println("detent");

            // If it's a different detent than before
            if (closestDetent != lastKnownDetent)
            {
                _mqttHandler.SendThrottleFor(currentLocoRoadName, throttleOfClosestDetent);
                lastKnownDetent = closestDetent;
            }
        }
        else if (measuredThrottle > throttleOfClosestDetent)
        {
            _qwiicMotorDriver.setDrive(THROTTLE_MOTOR_NUM, THROTTLE_DOWN, detentPower);
            // Serial.printf("down %d\n", detentPower);
        }
        else
        {
            _qwiicMotorDriver.setDrive(THROTTLE_MOTOR_NUM, THROTTLE_UP, detentPower);
            // Serial.printf("up %d\n", detentPower);
        }
    }
    else if (currentThrottleMode == ControllerMode::Unknown)
    {
        // Serial.println("Unknown...");
        ; // Do nothing
    }
}

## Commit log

2021-01-26 Started wiring up the mqtt interface for sounds.
2021-01-26 Added track voltage reporting through a voltage divider.
2021-02-26 Adjusting pins on the Wemos, to untangle wires.
2021-02-26 Use built-in LED to indicate whether connected to MQTT.
2021-03-10 Fix a lighting typo bug.
    [lightingDriver.cpp, lightingDriver.h]
2021-03-10 Added measurement of wheel RPMs.
2021-03-11 Improvements to filtering/processing of wheel rpms.
2021-03-12 Added a PID controller for speed control. Tries to match measured wheel RPMs to commanded wheel RPMs. Still needs tuning.
2021-03-12 Rearranging the PID equation into standard form.
2021-03-15 Added OTA updates. Working on tuning the PID controller.
2021-03-15 Switched to a better motor driver board. Tuned the PID more.
2021-03-16 Playing with PID controller.
2021-03-16 PID tuning
2021-03-17 Since I can predict the relationship between power and speed on straight track, I added a predicted bias term to the PID controller.
2021-03-18 PID tuning.
2021-03-23 Add protection into the reset command so that the motors don't run away at 100%.
    [mqttHandler.cpp]
2021-04-09 Adjust the scale of wheel RPMS to convert to scale MPH.
2021-05-10 Adjust PID values
2021-05-12 PID tuning for Alco RS-3
2021-05-14 More tuning of PID controller
2021-05-14 Firmware for tachometer calibration tool.
2021-05-18 Added images of the Tach Calibrator
2021-06-07 Added OLED display for listing out available locos, and button to switch between them.
2021-06-17 Control a loco's master switch from the panel.
2021-06-23 Panel: added button and LED for EngineOn.
2021-06-24 Started experimenting with the motorized rotary potentiometer. It'll be used for the reverser controls.
    [main.cpp, reverserController.cpp]
2021-06-24 Panel: added a reset functionality for the reverser.
    [mqttHandler.cpp, reverserController.cpp]
2021-06-28 Panel: send out reverser commands.
    [mqttHandler.cpp, reverserController.cpp]
2021-07-19 Panel: Implement cablights button.
2021-07-20 Panel: got bell button working.
2021-07-20 Panel: Added a second GPIO over I2C
2021-07-23 Sounds: Reverted to earlier version of Espressif8266 framework. New v3.0.0 caused problems for the audio library.
2021-08-03 Update the master switch and engine on to use the new lighted toggles.
2021-08-03 Started to wire up the throttle controller. It's now moving.
2021-08-04 Panel: make the throttle controller fully functional.
2021-08-06 Panel: Tweak the behavior of the throttle controller, so that it transitions cleanly between locos.
2021-08-06 Engine: The 3.0 version of the espressif8266 framework changed the range for analogWrites. It caused my trains to crash! AARGH! So I reverted to 2.x.
    [motorDriver.cpp]
2021-08-16 Panel: reorganize some wiring and GPIO connections.
2021-08-30 Adding more documentation on the different electronic boards.
2021-08-31 Added Fritzing sketches for audio board POCs, that would interface with conventional sound units.
    [WhistleControllerWithButtons.fzz, WhistleControllerWithESP8266.fzz, WhistleControllerWithTransistors.fzz]
2021-08-31 Panel: POC of adding programmatic resistance in the throttle lever.
2021-08-31 Added documentation on the whistle controller circuits.
2021-09-01 Adding fritzing diagrams and documentation on the pcb boards
    [EngineHat.fzz, WhistleControllerWithButtons.fzz, WhistleControllerWithESP8266.fzz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]
2021-10-12 Documentation of PCBs
    [EngineHat.fzz, PowerSupply.fzz]
2021-10-12 Documenting more PCBs
    [SoundHat.fzz]
2021-10-14 Added STL files for my RS-3 undercarriage.
    [Part1.stl, Part2.stl, Part3.stl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]
2021-10-14 More documentation
    [PowerSupply.fzz]
2021-10-19 Implement detents on the throttle control.
2021-10-26 Fix the re-sending of redundant reverser and headlight commands.
    [headlightsController.cpp, reverserController.cpp]
2021-11-16 Updated the STLs for the 3d printed parts.
    [LeftTank.stl, MainBox.stl, OuterBox.stl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]
2021-11-16 Fix bug in the slaveController. Improve performance of tach.
    [tachDriver.h]
2021-12-14 Tuning the PID controller
